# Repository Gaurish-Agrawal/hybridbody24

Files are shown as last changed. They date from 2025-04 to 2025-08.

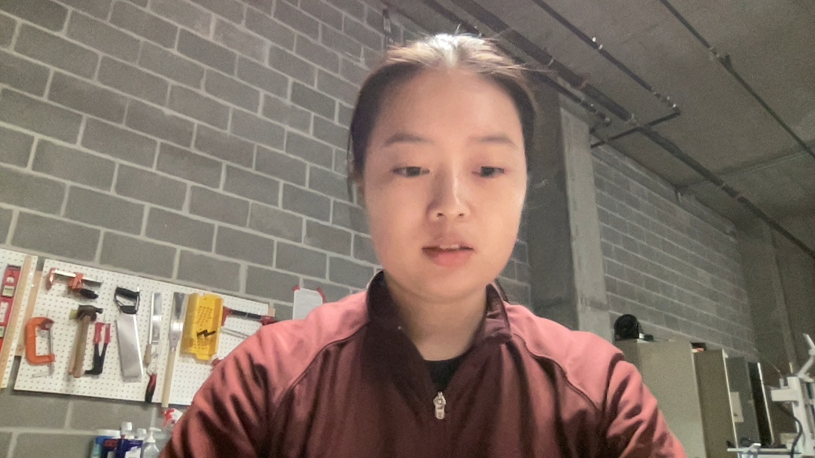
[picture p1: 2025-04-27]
Depth-Simulation/camera/temp_frame.jpg

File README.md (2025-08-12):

# Hybrid Body Suit

The **Hybrid Body Suit** is an assistive wearable designed to improve indoor navigation, spatial awareness, and safety for individuals with visual impairments or mobility challenges.

# Acknowledgments

- Inspired by challenges faced by the visually impaired community
- Full-length documentation and details can be shared based on circumstance.
- Developed by a team at **Washington University in St. Louis**

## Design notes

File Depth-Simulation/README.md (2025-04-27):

# VENV

terminal
python -m venv venv
source venv/bin/activate
conda deactivate #deactive base

# Run Code

python main.py --display --view overlay --debug
python main.py --display --view overlay --debug --detect-objects

# Blind Navigation Assistance System

A real-time navigation assistance system for visually impaired users that converts camera input into directional obstacle warnings using monocular depth estimation.

# Project Overview

This system uses a chest-mounted webcam (angled at ~45° downward) to detect obstacles in the user's path and provides directional feedback (N, NE, NW, E, W) to help with navigation. The core technology is monocular depth estimation using MiDaS, which allows depth perception from a single camera without specialized depth sensors.

# System Architecture

blind_navigation_assist/
├── main.py # Main script to orchestrate the pipeline
├── camera/
│ └── capture.py # Video capture functionality
├── depth_estimation/
│ ├── midas.py # MiDaS depth estimation models
│ └── normalize.py # Depth normalization utilities
├── obstacle_detection/
│ ├── ground_plane.py # Ground plane estimation logic
│ └── grid_segmentation.py # Grid-based obstacle detection
├── feedback/
│ └── output.py # Directional output (console/visual for prototype)
├── simulation/
│ ├── visualizer.py # Optional 3D visualization with Panda3D
│ └── performance.py # Performance monitoring
├── utils/
│ ├── config.py # Configuration settings
│ ├── calibration.py # Depth calibration utilities
│ └── helpers.py # Utility functions
└── requirements.txt # Python dependencies

# Pipeline Flow

1. Capture Frame:
   - Camera captures a frame (640×480 RGB image)
   - Webcam mounted at chest height, angled ~45° downward
2. Estimate Depth:
   - MiDaS model processes the frame to generate a depth map
   - Using lightweight models optimized for embedded devices
3. Detect Obstacles:
   - Ground plane estimation identifies the floor
   - Grid-based segmentation separates obstacles from ground
   - Obstacles represented as 3D boxes with position data
4. Map to Sectors:
   - Obstacles mapped to 5 directional sectors (N, NE, NW, E, W)
   - Each sector tracks the closest obstacle within detection range
5. Generate Feedback:
   - Console/visual output shows which sectors contain obstacles
   - Distance-based intensity (closer obstacles = stronger feedback)
6. Update Simulation (optional):
   - 3D visualization renders the detected obstacles
   - Useful for development and debugging

# Visualization System

## Views

- **Top-Down View**: Bird's-eye perspective showing obstacles around user
- **First-Person View**: Camera perspective with obstacle overlays
- **Depth Map View**: Colorized visualization of the depth map
- **Sector Map**: Visual representation of the 5 directional sectors

## Interactive Elements

- **Parameter Adjustment**: Sliders for thresholds and detection ranges
- **Recording**: Capture and replay scenarios for testing
- **Ground Truth Marking**: Manually mark obstacles for evaluation

# Data Flow

[Camera] → [Frame Buffer] → [MiDaS Model] → [Depth Map] → [Ground Plane Estimation]
↓
[Feedback Output] ← [Sector Mapping] ← [Obstacle Detection] ← [Non-Ground Mask]
↓
[Console/Visual Display]

# Implementation Details

## Depth Estimation

- Model Options:
  - dpt_levit_224: Fastest option, suitable for Raspberry Pi 4
  - dpt_swin2_tiny_256: Better quality, recommended for Raspberry Pi 5/Jetson Nano
  - midas_v21_small: Legacy option with OpenVINO support
- Processing Resolution: 224×224 or 256×256 (model dependent)
- Optimization: Model quantization and/or ONNX conversion for performance

## Ground Plane & Obstacle Detection

- Ground Plane Approach: Fixed-angle assumption with height threshold
- Detection Range: 0-2.5 meters (configurable)
- Distance Categories:
  - Close: 0-1m
  - Medium: 1-2m
  - Far: 2-2.5m

### Grid-Based Obstacle Segmentation

1. **Grid Creation**:

   - Divide depth map into cells (e.g., 16×12 grid)
   - Each cell represents approximately 20×20cm in physical space

2. **Cell Classification**:

   - Calculate average depth and height for each cell
   - Classify as ground/obstacle based on height threshold
   - Apply median filtering to reduce noise

3. **Obstacle Grouping**:
   - Use connected components algorithm to group adjacent obstacle cells
   - Calculate centroid and minimum distance for each obstacle group
   - Filter small groups (< 3 cells) to reduce false positives

## Directional Mapping

- Sectors:
  - North (N): Straight ahead (-15° to 15°)
  - Northeast (NE): Front-right (15° to 45°)
  - Northwest (NW): Front-left (-45° to -15°)
  - East (E): Right (45° to 90°)
  - West (W): Left (-90° to -45°)

## Calibration Procedure

1. **Camera Intrinsics**:

   - Use OpenCV's calibration tools with a checkerboard pattern
   - Store camera matrix and distortion coefficients in a configuration file

2. **Depth Scaling**:

   - Place objects at known distances (1m, 2m) from camera
   - Record depth values and establish a scaling function
   - Create a simple UI for this calibration step

3. **Ground Plane**:
   - Capture frames in an empty area with flat ground
   - Analyze depth gradient to establish baseline ground plane
   - Save parameters to configuration file

## Performance Considerations

- Target Hardware: Raspberry Pi 4/5 or Jetson Nano
- Frame Rate: Minimum 5 FPS for prototype, 10+ FPS target
- Optimization Techniques:
  - Lower resolution processing
  - Model quantization
  - Frame skipping if necessary
- Grid-based obstacle detection instead of DBSCAN

## Performance Optimization

### Model Optimization

- **Quantization**: Convert model to INT8 precision using PyTorch quantization
- **ONNX Conversion**: Export model to ONNX format for faster inference
- **TensorRT** (for Jetson): Convert ONNX model to TensorRT engine

### Processing Optimizations

- **Resolution Scaling**: Process depth at 256×192 or lower
- **Region of Interest**: Focus processing on central 60% of image
- **Temporal Consistency**: Skip full processing every n frames
- **Multithreading**: Separate capture, processing, and visualization threads

# Configuration Parameters

## Camera Settings

- `CAMERA_INDEX`: 0 (default webcam)
- `FRAME_WIDTH`: 640 pixels
- `FRAME_HEIGHT`: 480 pixels
- `CAMERA_ANGLE`: 45° (downward tilt)

## Depth Estimation

- `DEPTH_MODEL`: "dpt_levit_224" (options: "dpt_swin2_tiny_256", "midas_v21_small")
- `PROCESSING_WIDTH`: 224 pixels
- `PROCESSING_HEIGHT`: 224 pixels
- `DEPTH_SCALE_FACTOR`: 3.0 (calibrated value to convert to meters)

## Obstacle Detection

- `GROUND_HEIGHT_THRESHOLD`: 0.1 meters (tolerance for ground plane)
- `MIN_OBSTACLE_HEIGHT`: 0.05 meters (minimum height to be considered an obstacle)
- `GRID_CELLS_X`: 16 (horizontal grid divisions)
- `GRID_CELLS_Y`: 12 (vertical grid divisions)

## Feedback Settings

- `WARNING_DISTANCE_CLOSE`: 1.0 meter
- `WARNING_DISTANCE_MEDIUM`: 2.0 meters
- `WARNING_DISTANCE_FAR`: 2.5 meters

# Development Roadmap

## Phase 1: Core Pipeline

- Camera capture setup
- MiDaS model integration and testing
- Basic ground plane estimation
- Simple obstacle detection

## Phase 2: Directional Mapping

- Implement sector-based mapping
- Create console/visual output
- Add distance-based categorization

## Phase 3: Optimization & Testing

- Performance benchmarking
- Model and parameter optimization
- Controlled environment testing

## Phase 4: Visualization & Analysis

- Implement 3D visualization
- Add performance monitoring
- Create analysis tools for recorded data

# Testing Methodology

## Quantitative Evaluation

- **Detection Rate**: % of obstacles correctly identified
- **False Positive Rate**: Incorrect obstacle detections
- **Distance Accuracy**: Error in estimated distances vs. ground truth
- **Processing Time**: Breakdown of time spent in each pipeline stage

## Test Scenarios

1. **Static Environment**: Room with furniture at known positions
2. **Dynamic Objects**: People walking in front of the camera
3. **Edge Cases**: Low light, reflective surfaces, textureless walls

## Validation Process

1. Record ground truth obstacle positions
2. Run system on test scenarios
3. Compare detected obstacles with ground truth
4. Analyze performance metrics and adjust parameters

# Limitations & Future Work

## Current Limitations

- Indoor environments only
- Flat ground surfaces
- Fixed camera position
- No haptic hardware integration yet

## Future Enhancements

- Haptic belt integration
- IMU for camera orientation tracking
- Terrain handling (stairs, slopes)
- Object classification
- Moving obstacle tracking
- Audio feedback option

## Dependencies

- OpenCV: Camera capture and image processing
- PyTorch: MiDaS depth estimation
- NumPy: Numerical operations
- Panda3D: Optional 3D visualization
- ONNX Runtime (optional): Optimized inference

# Error Handling and Edge Cases

## Depth Estimation Failures

- Low-confidence regions marked and excluded from obstacle detection
- Temporal smoothing to handle intermittent estimation errors
- Fallback to previous frame's depth map when confidence is low

## Environmental Challenges

- Brightness adjustment for varying lighting conditions
- Detection confidence thresholds adjusted based on lighting quality
- Warning indicators when operating in suboptimal conditions

## System Failures

- Watchdog timer to detect and recover from processing hangs
- Graceful degradation when processing cannot keep up with frame rate
- User notification for critical system errors

# References

- MiDaS: https://github.com/isl-org/MiDaS
- Panda3D: https://www.panda3d.org/

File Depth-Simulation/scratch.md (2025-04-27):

# Plan for Depth-Based Proximity Bar Implementation

## Background and Motivation

The goal is to create a low-latency proximity detection system using monocular depth estimation that provides a simple but effective visualization of obstacles in front of the user. The system will use a vertical proximity bar that fills from top to bottom as objects get closer to the user, with corresponding color changes to indicate urgency.

## Key Challenges and Analysis

1. Latency reduction in the depth estimation pipeline
2. Creating an intuitive proximity bar visualization
3. Ensuring stable detection without excessive temporal smoothing
4. Properly mapping depth values to the proximity bar

## High-level Task Breakdown

### Task 1: Optimize MiDaS for Lower Latency

- Update `midas.py` to reduce input resolution (160x120 or similar)
- Adjust EMA filter alpha value for less smoothing but still prevent flickering
- Ensure depth values are properly clamped between 0.5m and 5.0m
- Success criteria: Depth estimation should run at >15 FPS with stable output

### Task 2: Create ProximityBar Class

- Create new file `simulation/visualization/proximity_bar.py`
- Implement ProximityBar class with the following features:
  - Vertical bar visualization (user at bottom, 5m range at top)
  - Fill from top to bottom as objects approach
  - Color gradient (green→yellow→red) based on distance
  - Configurable dimensions and thresholds
- Success criteria: Bar should display and update correctly with test values

### Task 3: Integrate Proximity Bar into Main Loop

- Modify `main.py` to create and display the proximity bar
- Extract nearest object information from depth map
- Update proximity bar based on nearest point
- Add console output of "haptic feedback invoked" when objects are within 0.5-1.5m
- Success criteria: System should display camera feed, depth map, and proximity bar simultaneously

### Task 4: Testing and Refinement

- Test system with various objects at different distances
- Adjust thresholds and visualization parameters as needed
- Optimize performance if still experiencing latency issues
- Success criteria: System reliably detects objects and provides stable visualization

## Project Status Board

- [x] Task 1: Optimize MiDaS for Lower Latency
- [x] Task 2: Create ProximityBar Class
- [x] Task 3: Integrate Proximity Bar into Main Loop
- [x] Task 4: Testing and Refinement (Initial improvements completed)

## Executor's Feedback or Assistance Requests

The implementation has been completed with the following optimizations:

1. Added performance metrics using an exponential moving average for depth estimation
2. Improved first frame handling to ensure smoother startup
3. Added a debug flag to control verbose output
4. Implemented frame skipping to reduce CPU load

To run the system with these improvements:

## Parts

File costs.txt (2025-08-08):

Estimated Manufacturing Costs through year

Item	Quantity	Unit Cost ($)	Total Cost ($)
TCA9548A I2C Multiplexer	2	6.95	13.90
Seeed Studio XIAO ESP32S3 Camera	1	13.99	13.99
Teyleten Robot TOF400C VL53L1X 4M	8	15.88	127.04
Arduino Portenta H7 Lite Connected	1	106.80	106.80
Safety Vest Black	1	14.99	14.99
ULN2803A Darlington Transistor Arrays	1	6.99	6.99
6 Pcs DC Coreless Vibration Motors	2	9.99	19.98
Heavy Duty Nylon Canvas Black	2	12.60	24.20
2 Yards Plastic Snaps	1	6.99	6.99
Super Glue Liquid, 2 Pack	1	2.68	2.68
Breadboard Jumper Wires Kit	1	7.99	7.99
24 AWG Flexible Silicone Wire, 30ft	1	15.39	15.39
Solderable PCB Breadboard	1	9.49	9.49
3.7V Lipo Battery 1000mAh (2 pack)	2	9.89	19.78
MT3608 Boost Converter (Pack of 5)	1	5.95	5.95
100ft 22AWG 4pin RGB Wire	1	13.99	13.99
900 Pcs Heat Shrink Tubing Kit	1	6.59	6.59
Clear Lens Glasses Frame	1	9.99	9.99
USB-C Lithium Battery Charger (10 pack)	1	7.99	7.99
Raspberry Pi 4 Model B	1	58.99	58.99
Small Rare Earth Neodymium Magnets (60 pcs)	1	6.98	6.98
Quality Assurance (30–45 mins @ $20/hr)	—	—	15.00
Assembly Labor (2 hrs @ $15/hr)	—	—	30.00

Total Cost  $545.06

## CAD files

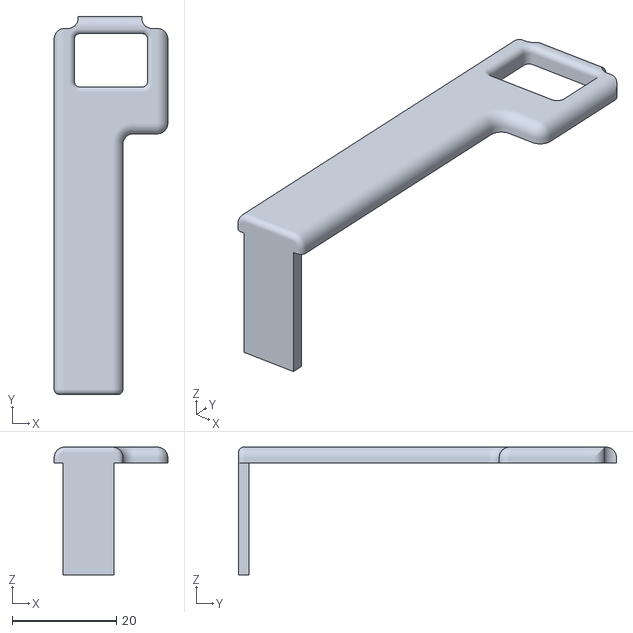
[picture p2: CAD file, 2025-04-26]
CAD/Camera Holder on Glasses/R2 Thin.stl
21.8 x 72.5 x 24.5

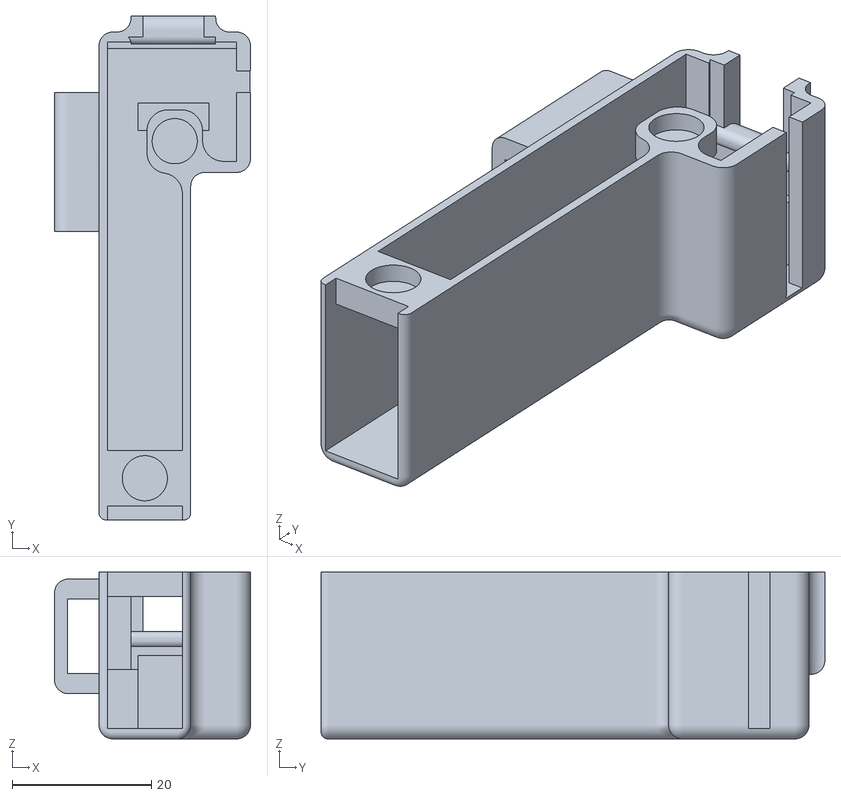
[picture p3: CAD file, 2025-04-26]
CAD/Camera Holder on Glasses/R1 Thin.stl
28.2 x 72.5 x 24.0

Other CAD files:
CAD/Camera Holder on Glasses/L2 Thin.stl
CAD/Camera Holder on Glasses/L1 Thin.stl

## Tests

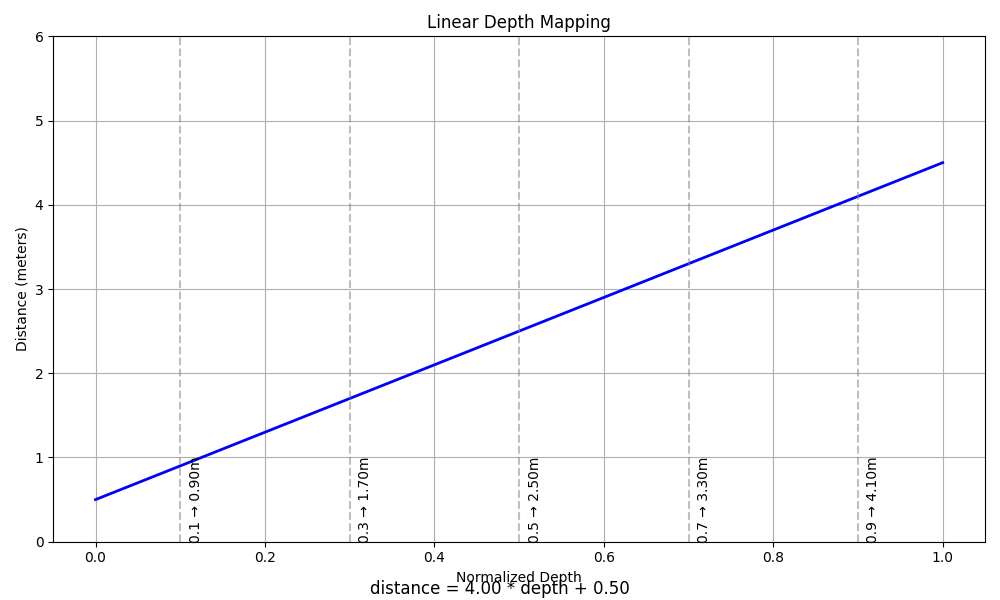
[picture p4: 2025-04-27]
Depth-Simulation/calibration_curve.png

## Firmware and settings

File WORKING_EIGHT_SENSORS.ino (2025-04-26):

#include <Wire.h>
#include "Adafruit_VL53L1X.h"

#define TCAADDR 0x70

Adafruit_VL53L1X vl53 = Adafruit_VL53L1X();

// Array of active channels
uint8_t channels[] = {0, 1, 2, 3, 4, 5, 6, 7};
const uint8_t numChannels = sizeof(channels) / sizeof(channels[0]);

void tcaselect(uint8_t i) {
  if (i > 7) return;
  Wire.beginTransmission(TCAADDR);
  Wire.write(1 << i);
  Wire.endTransmission();
}

void setup() {
  Serial.begin(115200);
  while (!Serial);
  delay(1000);

  Wire.begin();

  Serial.println("Initializing sensors on all channels");

  for (uint8_t c = 0; c < numChannels; c++) {
    uint8_t channel = channels[c];
    tcaselect(channel);
    delay(400);
    Serial.print("Testing channel: ");
    Serial.println(channels[c]);
    if (!vl53.begin(0x29, &Wire)) {
      Serial.print("Sensor on channel "); Serial.print(channel); Serial.println(" not found");
    } else {
      Serial.print("Sensor on channel "); Serial.print(channel); Serial.println(" initialized");
      vl53.startRanging();
    }
    delay(100);
  }

  Serial.println("Setup complete.");
}

void loop() {
  for (uint8_t c = 0; c < numChannels; c++) {
    uint8_t channel = channels[c];
    tcaselect(channel);

    if (vl53.dataReady()) {
      uint16_t distance = vl53.distance();
      Serial.print("Sensor "); Serial.print(channel); Serial.print(": ");
      Serial.print(distance); Serial.println(" mm");
      vl53.clearInterrupt();
    } else {
      Serial.print("Sensor "); Serial.print(channel); Serial.println(": Data not ready");
    }

    delay(50);
  }

  Serial.println("---");
  delay(500);
}

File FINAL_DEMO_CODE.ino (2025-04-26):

#include <Wire.h>
#include <WiFi.h>
#include <WiFiClient.h>
#include <ArduinoHttpClient.h>
#include "Adafruit_VL53L1X.h"

#define TCAADDR 0x70
#define THRESHOLD_MM 50

// Access Point credentials
char ssid[] = "PortentaAccess";
char pass[] = "1234abcd";

// Target client (connected to AP)
const char* targetIP = "192.168.3.2";  // IP of laptop connected to AP
int targetPort = 5000;

WiFiClient wifiClient;
HttpClient httpClient = HttpClient(wifiClient, targetIP, targetPort);

// Sensors and motors setup
Adafruit_VL53L1X vl53 = Adafruit_VL53L1X();
uint8_t sensorChannels[] = {0, 1, 2, 3, 4, 5, 6, 7};  // N, NE, E, SE, S, SW, W, NW
uint8_t motorPins[]     = {0, 1, 2, 3, 4, 5, 6, 7};    // NE, N, E, SE, S, SW, W, NW
const uint8_t numSensors = sizeof(sensorChannels) / sizeof(sensorChannels[0]);

int status = WL_IDLE_STATUS;

void tcaselect(uint8_t i) {
  if (i > 7) return;
  Wire.beginTransmission(TCAADDR);
  Wire.write(1 << i);
  Wire.endTransmission();
}

void setup() {
  Serial.begin(115200);
  while (!Serial);
  delay(1000);

  Wire.begin();

  // Setup motor pins
  for (uint8_t i = 0; i < numSensors; i++) {
    pinMode(motorPins[i], OUTPUT);
    digitalWrite(motorPins[i], LOW);
  }

  // Initialize sensors
  for (uint8_t i = 0; i < numSensors; i++) {
    tcaselect(sensorChannels[i]);
    delay(400);
    if (!vl53.begin(0x29, &Wire)) {
      Serial.print("Sensor "); Serial.print(sensorChannels[i]); Serial.println(" not found");
    } else {
      vl53.startRanging();
      Serial.print("Sensor "); Serial.print(sensorChannels[i]); Serial.println(" initialized");
    }
  }

  // Start Access Point
  Serial.println("==================================================");
  Serial.print("Attempting to start AP: "); Serial.println(ssid);
  status = WiFi.beginAP(ssid, pass);
  delay(5000);

  if (status != WL_AP_LISTENING) {
    Serial.println("❌ Failed to start Access Point!");
  } else {
    Serial.println("✅ Access Point started successfully.");
  }

  Serial.print("Portenta AP IP address: ");
  Serial.println(WiFi.localIP());
  Serial.println("==================================================");
}

void loop() {
  for (uint8_t i = 0; i < numSensors; i++) {
    uint8_t sensorChan = sensorChannels[i];
    uint8_t motorPin = motorPins[i];

    tcaselect(sensorChan);

    if (vl53.dataReady()) {
      uint16_t distance = vl53.distance();
      vl53.clearInterrupt();

      Serial.print("Sensor "); Serial.print(sensorChan); Serial.print(" (");
      Serial.print(motorPin); Serial.print(") distance: ");
      Serial.print(distance); Serial.println(" mm");

      // Control motor
      if (motorPin == 7) {
        // Pin 7 (NW) no PWM
        if (distance < 40) {
          digitalWrite(motorPin, HIGH);
        } else {
          digitalWrite(motorPin, LOW);
        }
      } else {
        if (distance < 10) {
          analogWrite(motorPin, 255); // Full power
        } else if (distance < 40) {
          analogWrite(motorPin, 128); // Half power
        } else {
          analogWrite(motorPin, 0);   // Off
        }
      }

      // Send HTTP GET to client
      if (WiFi.status() == WL_AP_CONNECTED) {
        String path = "/sensorUpdate?channel=" + getDirectionName(i) + "&distance=" + String(distance);

        Serial.print("📡 Sending to client: ");
        Serial.println(path);

        httpClient.beginRequest();
        httpClient.get(path);
        httpClient.endRequest();

        int statusCode = httpClient.responseStatusCode();
        String response = httpClient.responseBody();

        Serial.print("HTTP status: ");
        Serial.println(statusCode);
        Serial.println("Response:");
        Serial.println(response);

        wifiClient.stop();  // 🔥 Critical: reset TCP connection after each request
      } else {
        Serial.println("⚠️ No client connected yet.");
      }

    } else {
      Serial.print("Sensor "); Serial.print(sensorChan); Serial.println(": no data");
      digitalWrite(motorPin, LOW);
    }

    delay(100);
  }

  delay(300); // Extra time between full rounds
}

String getDirectionName(uint8_t sensorIndex) {
  switch (sensorIndex) {
    case 0: return "NW";
    case 1: return "N";
    case 2: return "W";
    case 3: return "S";
    case 4: return "SE";
    case 5: return "NE";
    case 6: return "E";
    case 7: return "SW";
    default: return "UNK";
  }
}

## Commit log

2024-11-08 Testing detection + Audio via camera sensor
2024-11-23 Add arduino code for haptic control test
2025-01-25 Added Arduino code
2025-02-15 Haptic Motor Multiplexer
    Added code for testing all channels of multiplexer
2025-02-15 belt+haptic simulation
    indoor navigation haptics simulation with belt visual and path mapping
2025-02-19 multiple haptic motors test with directions
2025-03-25 Create simulation-pulse.py
    New collision logic. Using 8 radii circles with isocenter at each sensor. Also smaller collision radius, but still has some overlap. Just for testing purposes.
2025-04-07 Create receiver.py
    Code to visualize data from sensors. Only four directions rn.
2025-04-07 Code for sensor module
2025-04-07 current code for haptics module
2025-04-09 Update receiver.py
    updated python code to receive data from sensors
2025-04-26 FINAL SIM AND ARDUINO CODE
2025-04-26 Camera Holder CAD
    [L1 Thin.stl, L2 Thin.stl, R1 Thin.stl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]
